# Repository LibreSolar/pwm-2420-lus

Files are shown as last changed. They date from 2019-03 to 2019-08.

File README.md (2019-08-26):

# PWM Solar Charge Controller (10-20A)

 Tested prototype, only minor issues left.

This PWM charge controller is cheaper than the MPPT charge controllers, as it does not contain the internal powerful DC/DC converter necessary for MPPT. The lower production cost and easy manufacturing with larger SMD components makes it ideally suited for solar home systems (SHS) for rural electrification.

The design allows to use either SMD MOSFETs or TO220 THT MOSFETs, which can be easily attached to a heat sink.

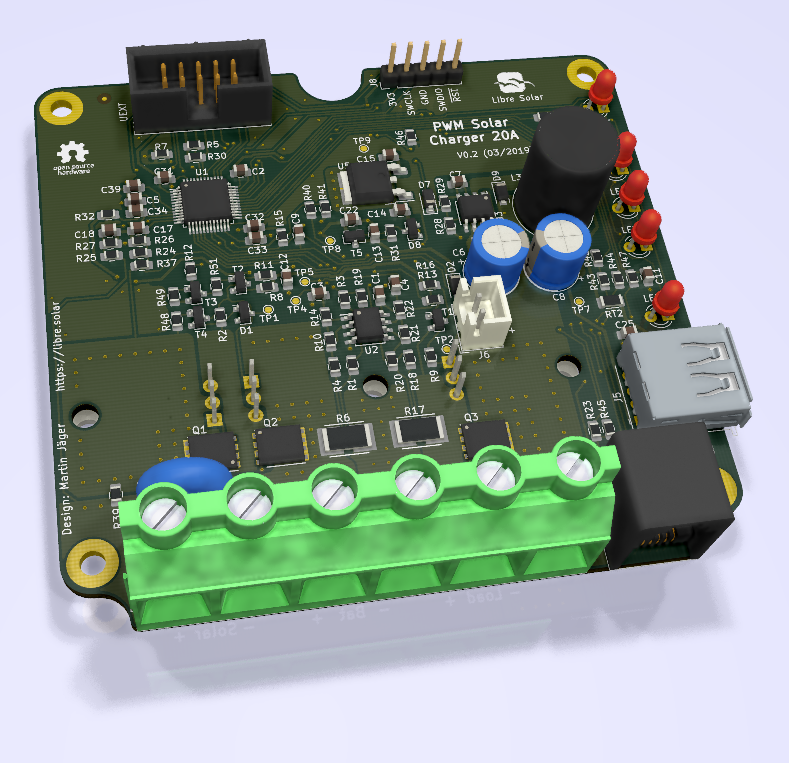
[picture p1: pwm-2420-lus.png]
PWM charge controller PCB


Schematic: [PDF file](pwm-2420-lus.pdf) in repository

Gerber files: [PCB ordering](http://libre.solar/docs/pcb_ordering) documentation

Bill of Materials: [BOM export](http://libre.solar/docs/bom) from KiCAD

Firmware: [Charge Controller Firmware](https://github.com/LibreSolar/charge-controller-firmware) repository

## Features:
- 12V/24V battery voltage
- Up to 20A max. charge current (depending on selected MOSFETs)
- 55V max. solar input
- 32bit ARM MCU (STM32L072)
- Expandable via Olimex Universal Extension Connector (UEXT) featuring
   I2C, Serial and SPI interface (e.g. used for display, WIFI communication, etc.)
- USB charging (single port)
- Low-side load switching

## Built-in protection
- Overvoltage
- Undervoltage
- Overcurrent
- PV short circuit
- PV reverse polarity (for max. module open circuit voltage of around 40V)
- Battery reverse polarity

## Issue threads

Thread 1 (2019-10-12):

Wrong load output current reading in v0.3

martinjaeger, 2019-10-12:
The voltage behind the output filter of the load current sense amplifier is used by a resistor divider to provide a threshold for the overcurrent comparator. This changes also the value read by the ADC, as it influences the overall output impedance.

Preliminary solution: Scale current sensor reading by a factor of  (12k+8.2k)/(39k+12k+8.2k) = 0.341.

Solution for next PCB revision: Separate signal for comparator and for current measurement right at the opamp output and not after the filter.

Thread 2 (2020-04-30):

Unstable power supply for battery voltages around 30V

martinjaeger, 2020-04-30:
See description of issue and solutions in Libre Solar forum:

https://talk.libre.solar/t/pwm2420-lus-for-battery-voltages-24v/

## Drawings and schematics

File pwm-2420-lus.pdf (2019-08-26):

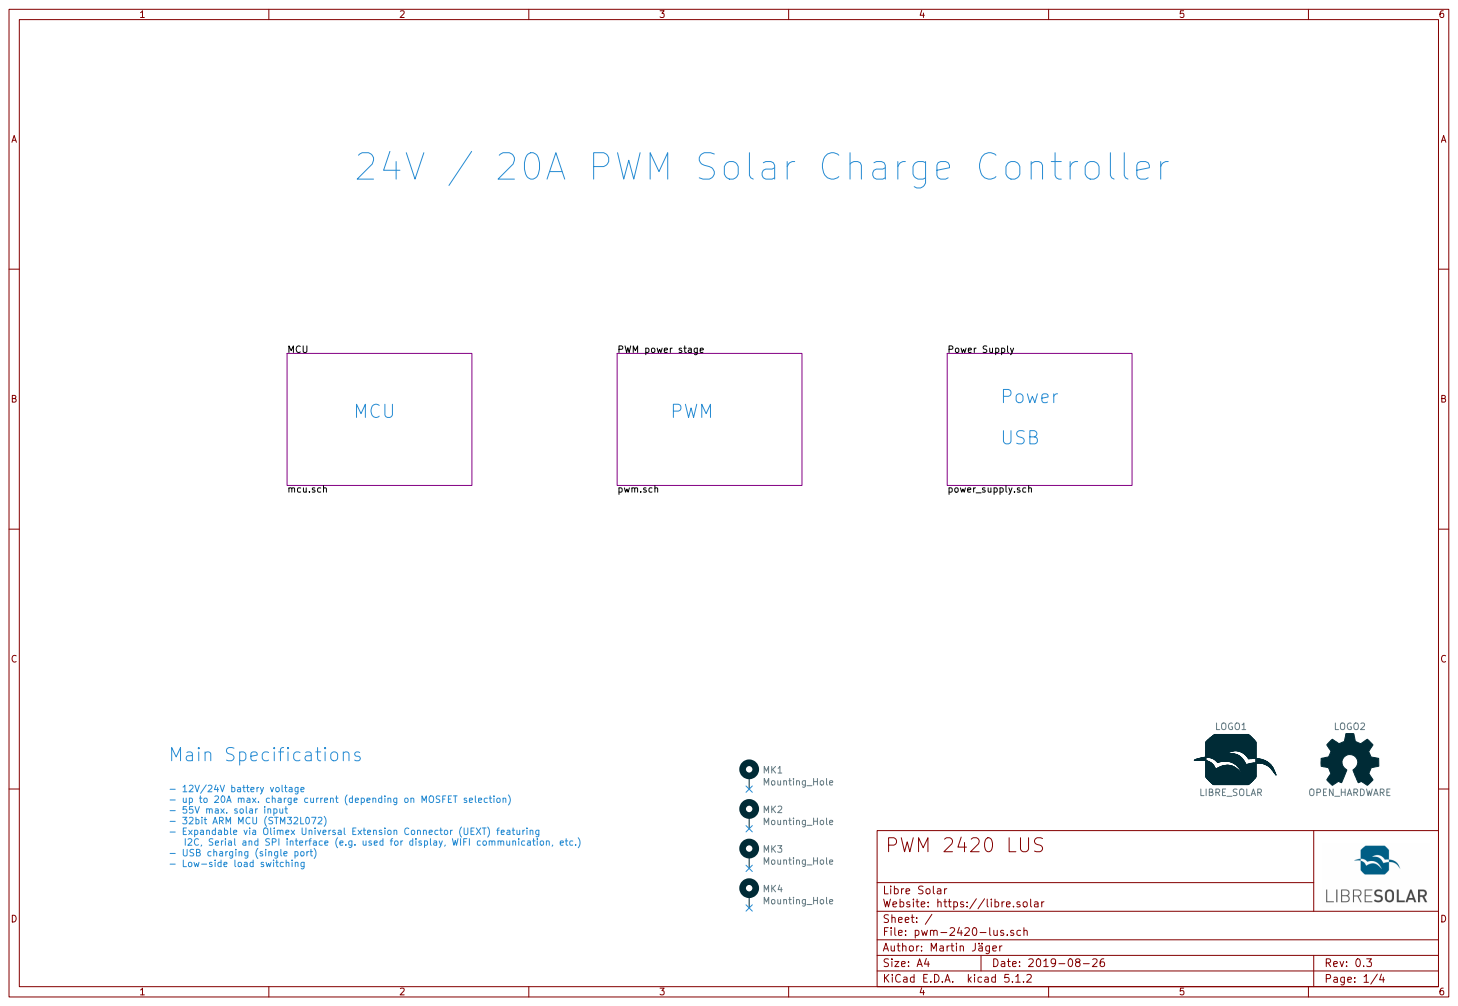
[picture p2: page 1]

24V / 20A PWM Solar Charge Controller

- 12V/24V battery voltage
- up to 20A max. charge current (depending on MOSFET selection)
- 55V max. solar input
- 32bit ARM MCU (STM32L072)
- Expandable via Olimex Universal Extension Connector (UEXT) featuring
I2C, Serial and SPI interface (e.g. used for display, WIFI communication, etc.)
- USB charging (single port)
- Low-side load switching

File: pwm-2420-lus.sch Sheet: / Libre Solar Author: Martin Jäger
Website: https://libre.solar

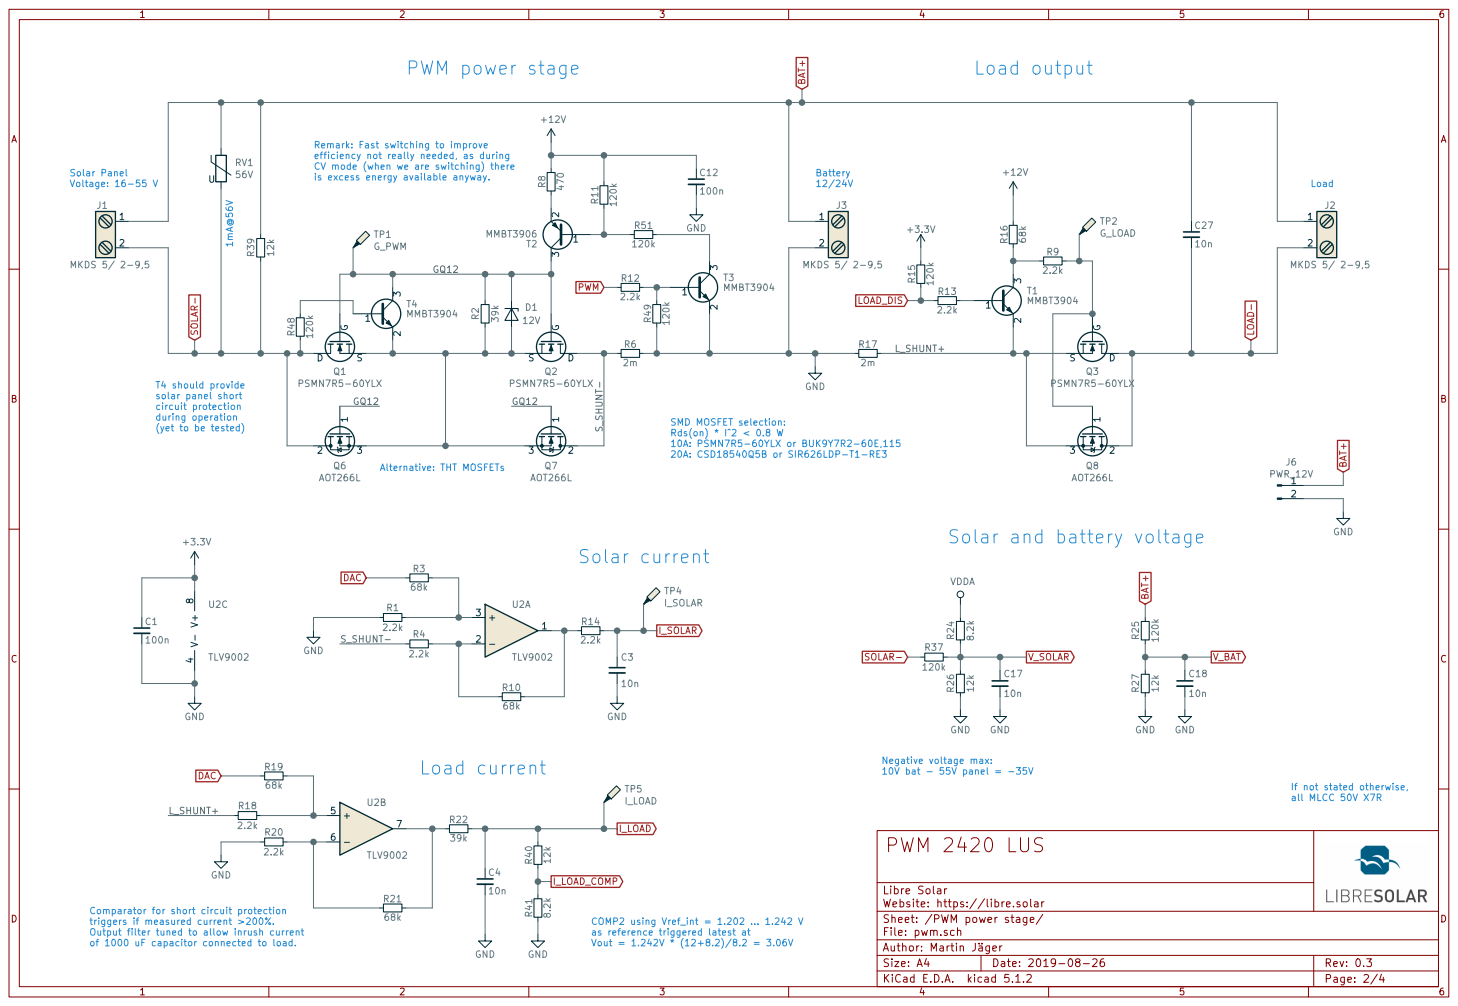
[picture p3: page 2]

20A: CSD18540Q5B or SIR626LDP-T1-RE3 Remark: Fast switching to improve
efficiency not really needed, as during
CV mode (when we are switching) there

J2 MKDS 5/ 2-9,5 Solar Panel Voltage: 16-55 V

2 3 T3MMBT3904 R11 120k SMD MOSFET selection: Rds(on) * I^2 < 0.8 W

solar panel short
circuit protection
during operation
(yet to be tested)

10n Solar and battery voltage

If not stated otherwise, all MLCC 50V X7R

Sheet: /PWM power stage/ Libre Solar Author: Martin Jäger
Website: https://libre.solar
File: pwm.sch

Comparator for short circuit protection
triggers if measured current >200%.
Output filter tuned to allow inrush current

as reference triggered latest at
Vout = 1.242V * (12+8.2)/8.2 = 3.06V

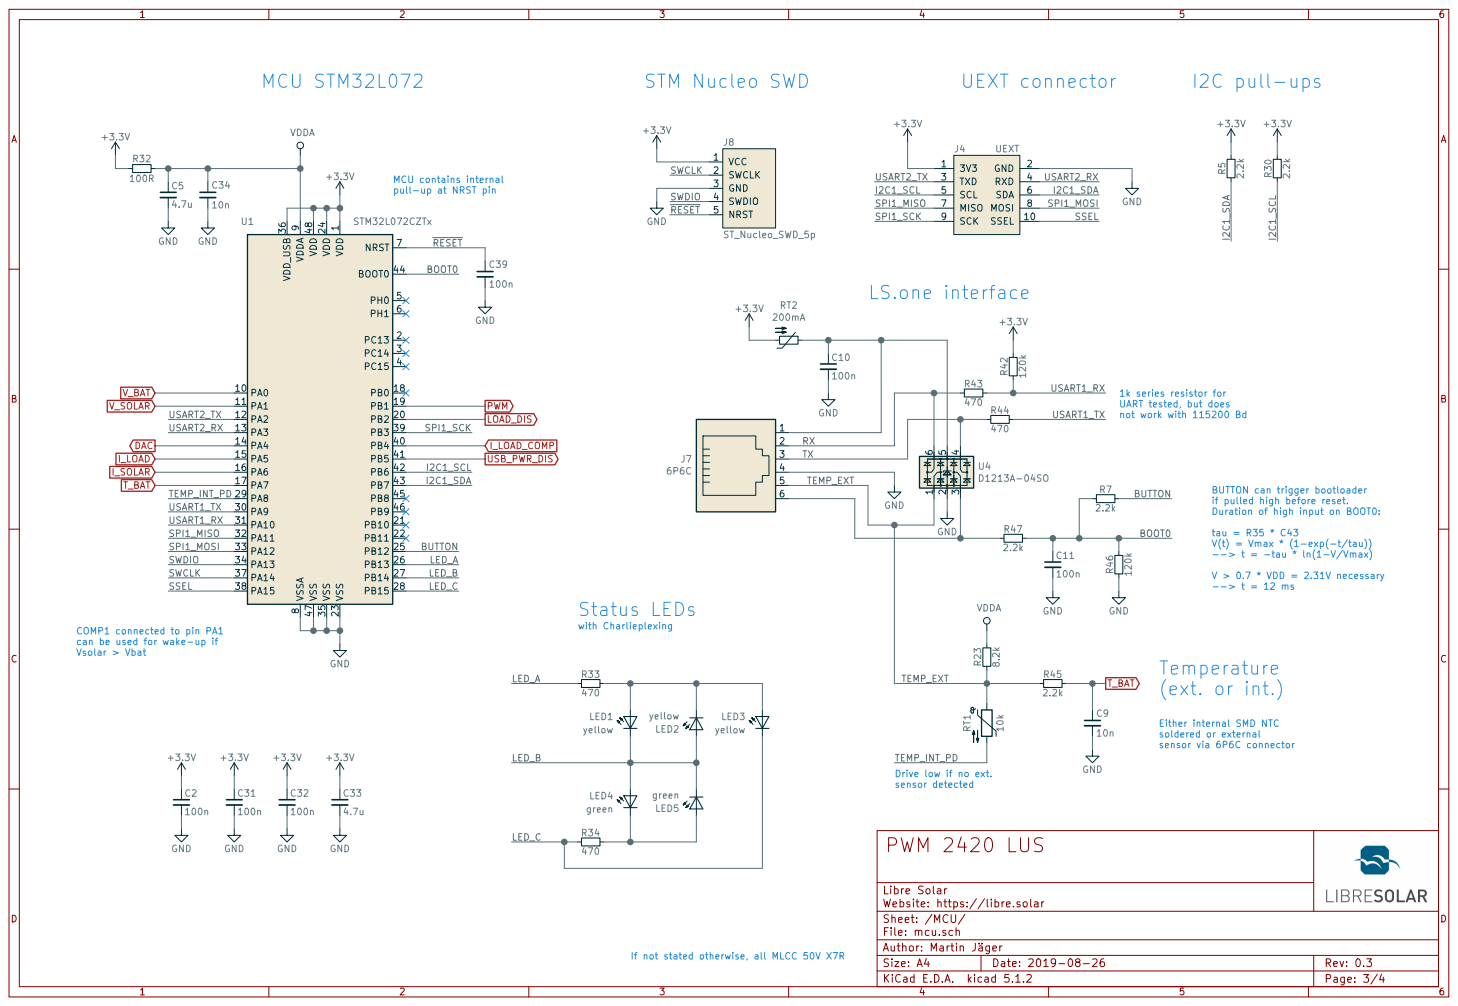
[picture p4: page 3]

100n GND MCU contains internal pull-up at NRST pin

9 VDD_USB 36 VSS 23 VSS 35 VSS 47 VSSA

soldered or external sensor via 6P6C connector LS.one interface
USART1_TX USART1_RX R45

1k series resistor for UART tested, but does not work with 115200 Bd +3.3V RX

BUTTON can trigger bootloader
if pulled high before reset.
Duration of high input on BOOT0:

tau = R35 * C43 V(t) = Vmax * (1-exp(-t/tau))

can be used for wake-up if Vsolar > Vbat

Drive low if no ext. sensor detected

File: mcu.sch Sheet: /MCU/ Libre Solar Author: Martin Jäger

If not stated otherwise, all MLCC 50V X7R

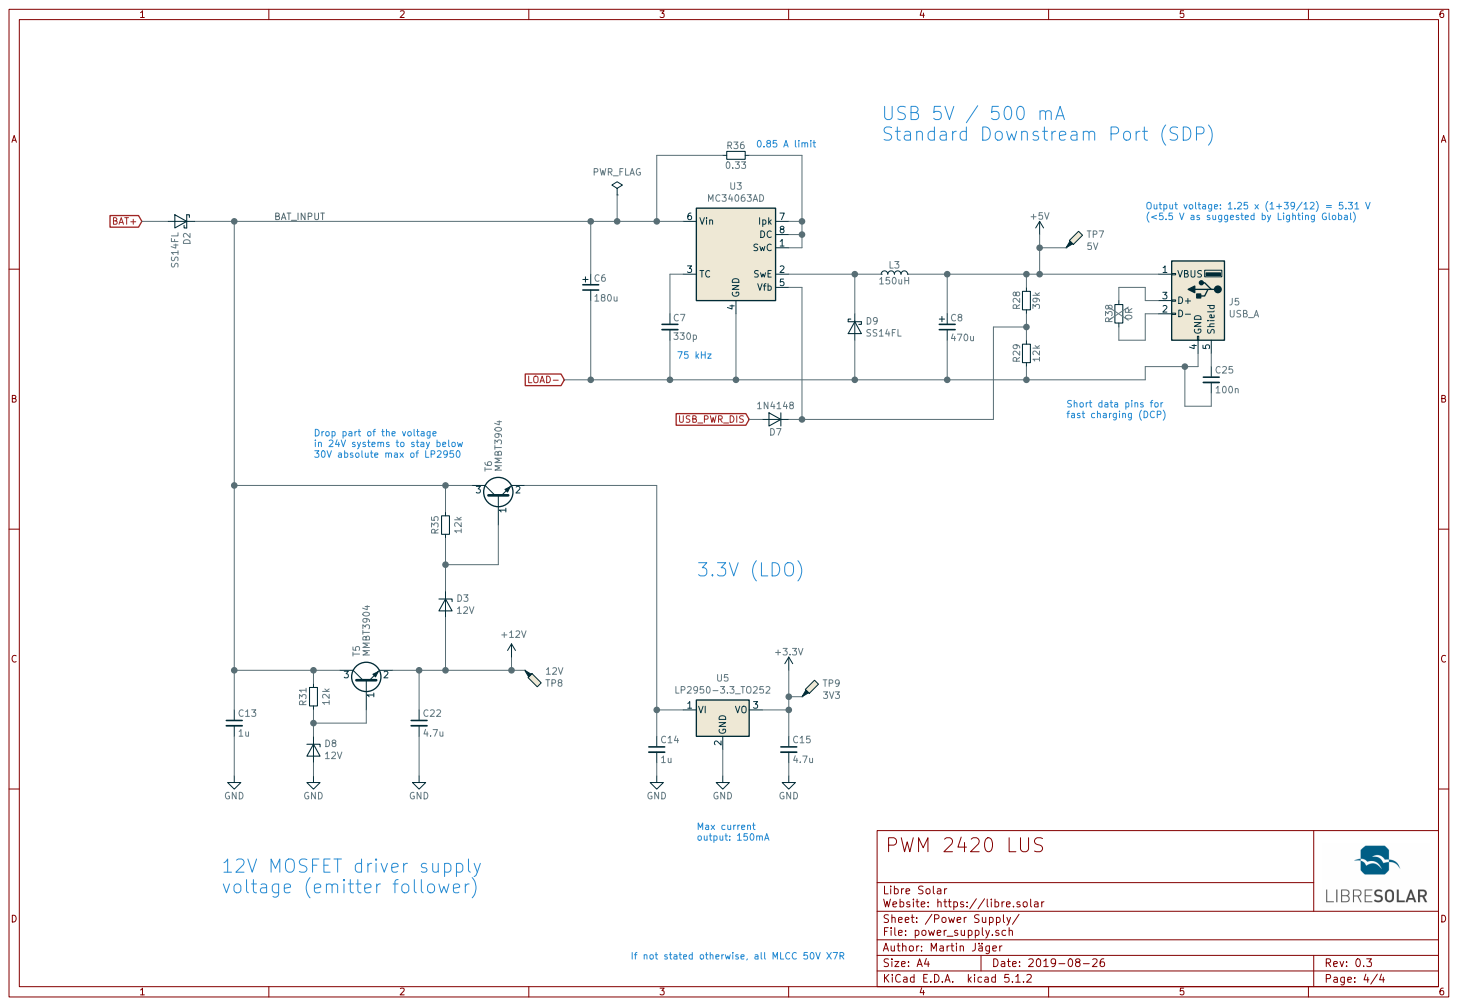
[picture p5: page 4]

Output voltage: 1.25 x (1+39/12) = 5.31 V
(<5.5 V as suggested by Lighting Global) C25

Short data pins for

Drop part of the voltage
in 24V systems to stay below

Sheet: /Power Supply/ Libre Solar Author: Martin Jäger

If not stated otherwise, all MLCC 50V X7R

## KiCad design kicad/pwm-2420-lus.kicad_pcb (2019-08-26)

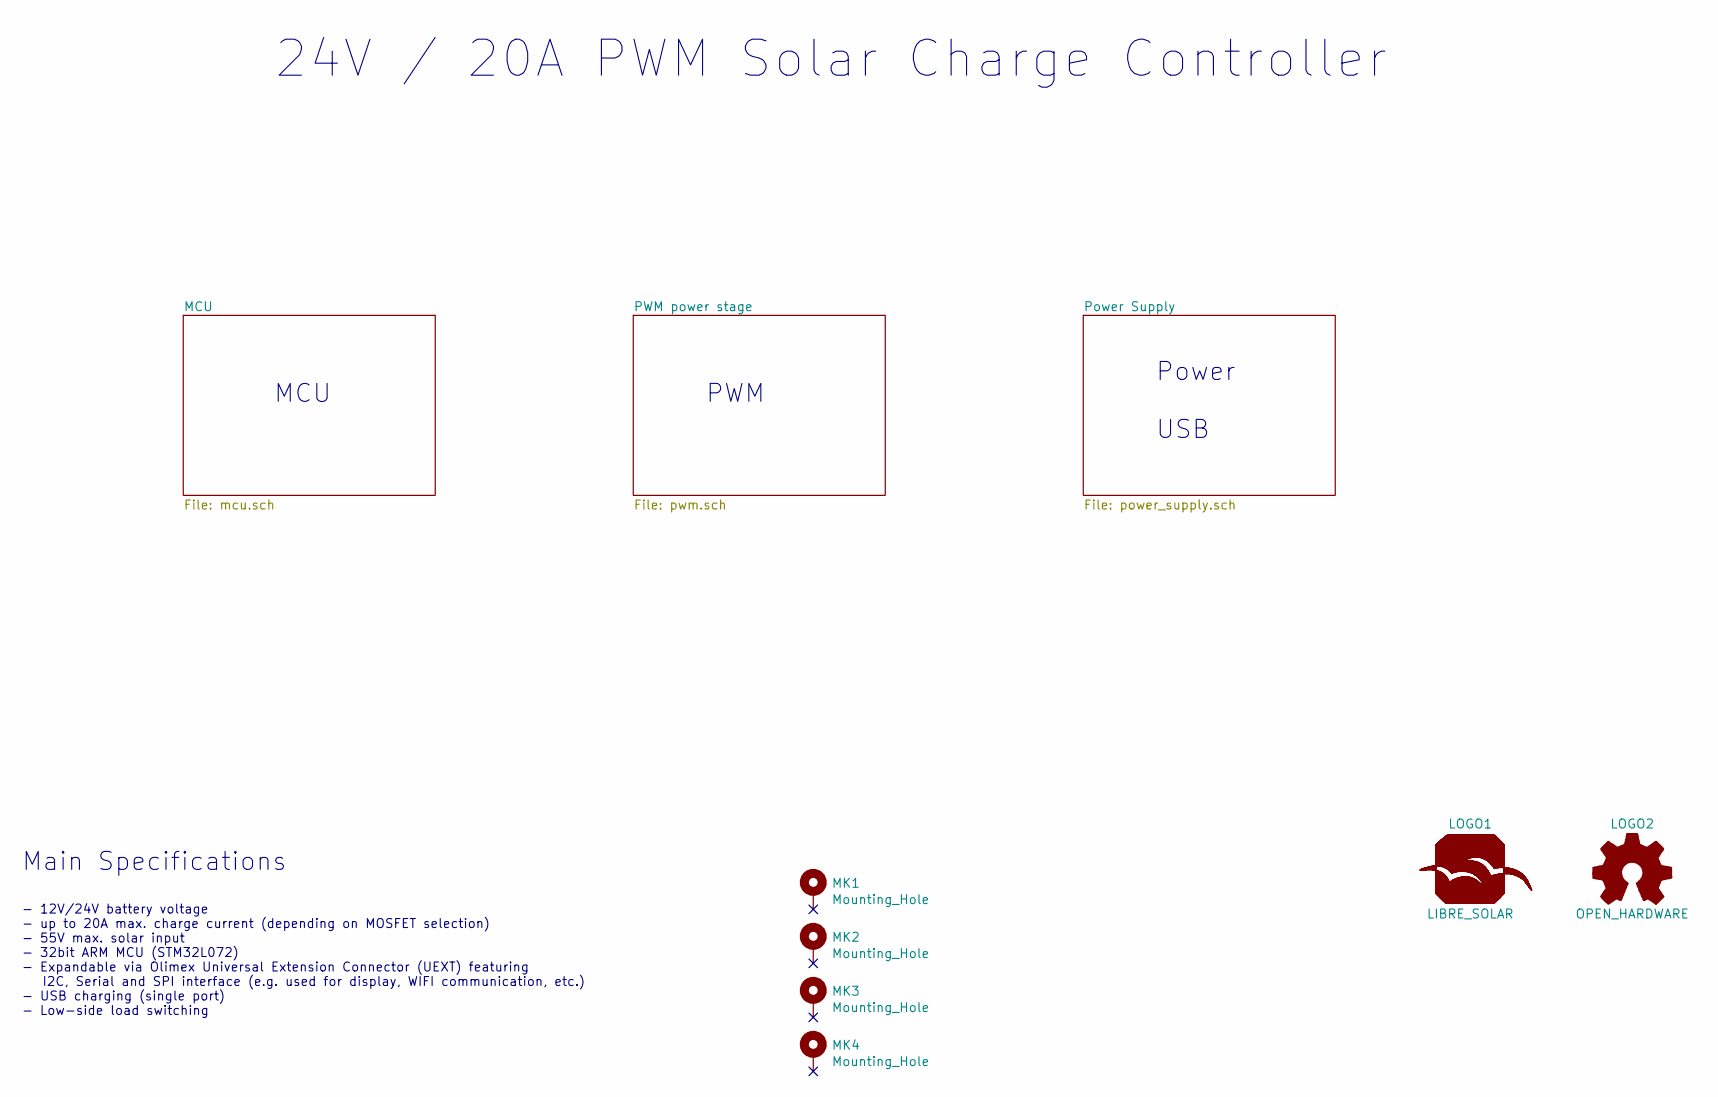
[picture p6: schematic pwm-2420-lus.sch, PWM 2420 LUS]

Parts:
LOGO1: LIBRE_SOLAR; LIBRESOLAR_LOGO
LOGO2: OPEN_HARDWARE; OSHW-Logo_5.7x6mm_SilkScreen
MK1, MK2, MK3, MK4: Mounting_Hole; MountingHole_3.2mm_M3_Pad

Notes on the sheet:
24V / 20A PWM Solar Charge Controller
Main Specifications
- 12V/24V battery voltage - up to 20A max. charge current (depending on MOSFET selection) - 55V max. solar input - 32bit ARM MCU (STM32L072) - Expandable via Olimex Universal Extension Connector (UEXT) featuring I2C, Serial and SPI interface (e.g. used for display, WIFI communication, etc.) - USB c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
PWM
MCU
Power USB

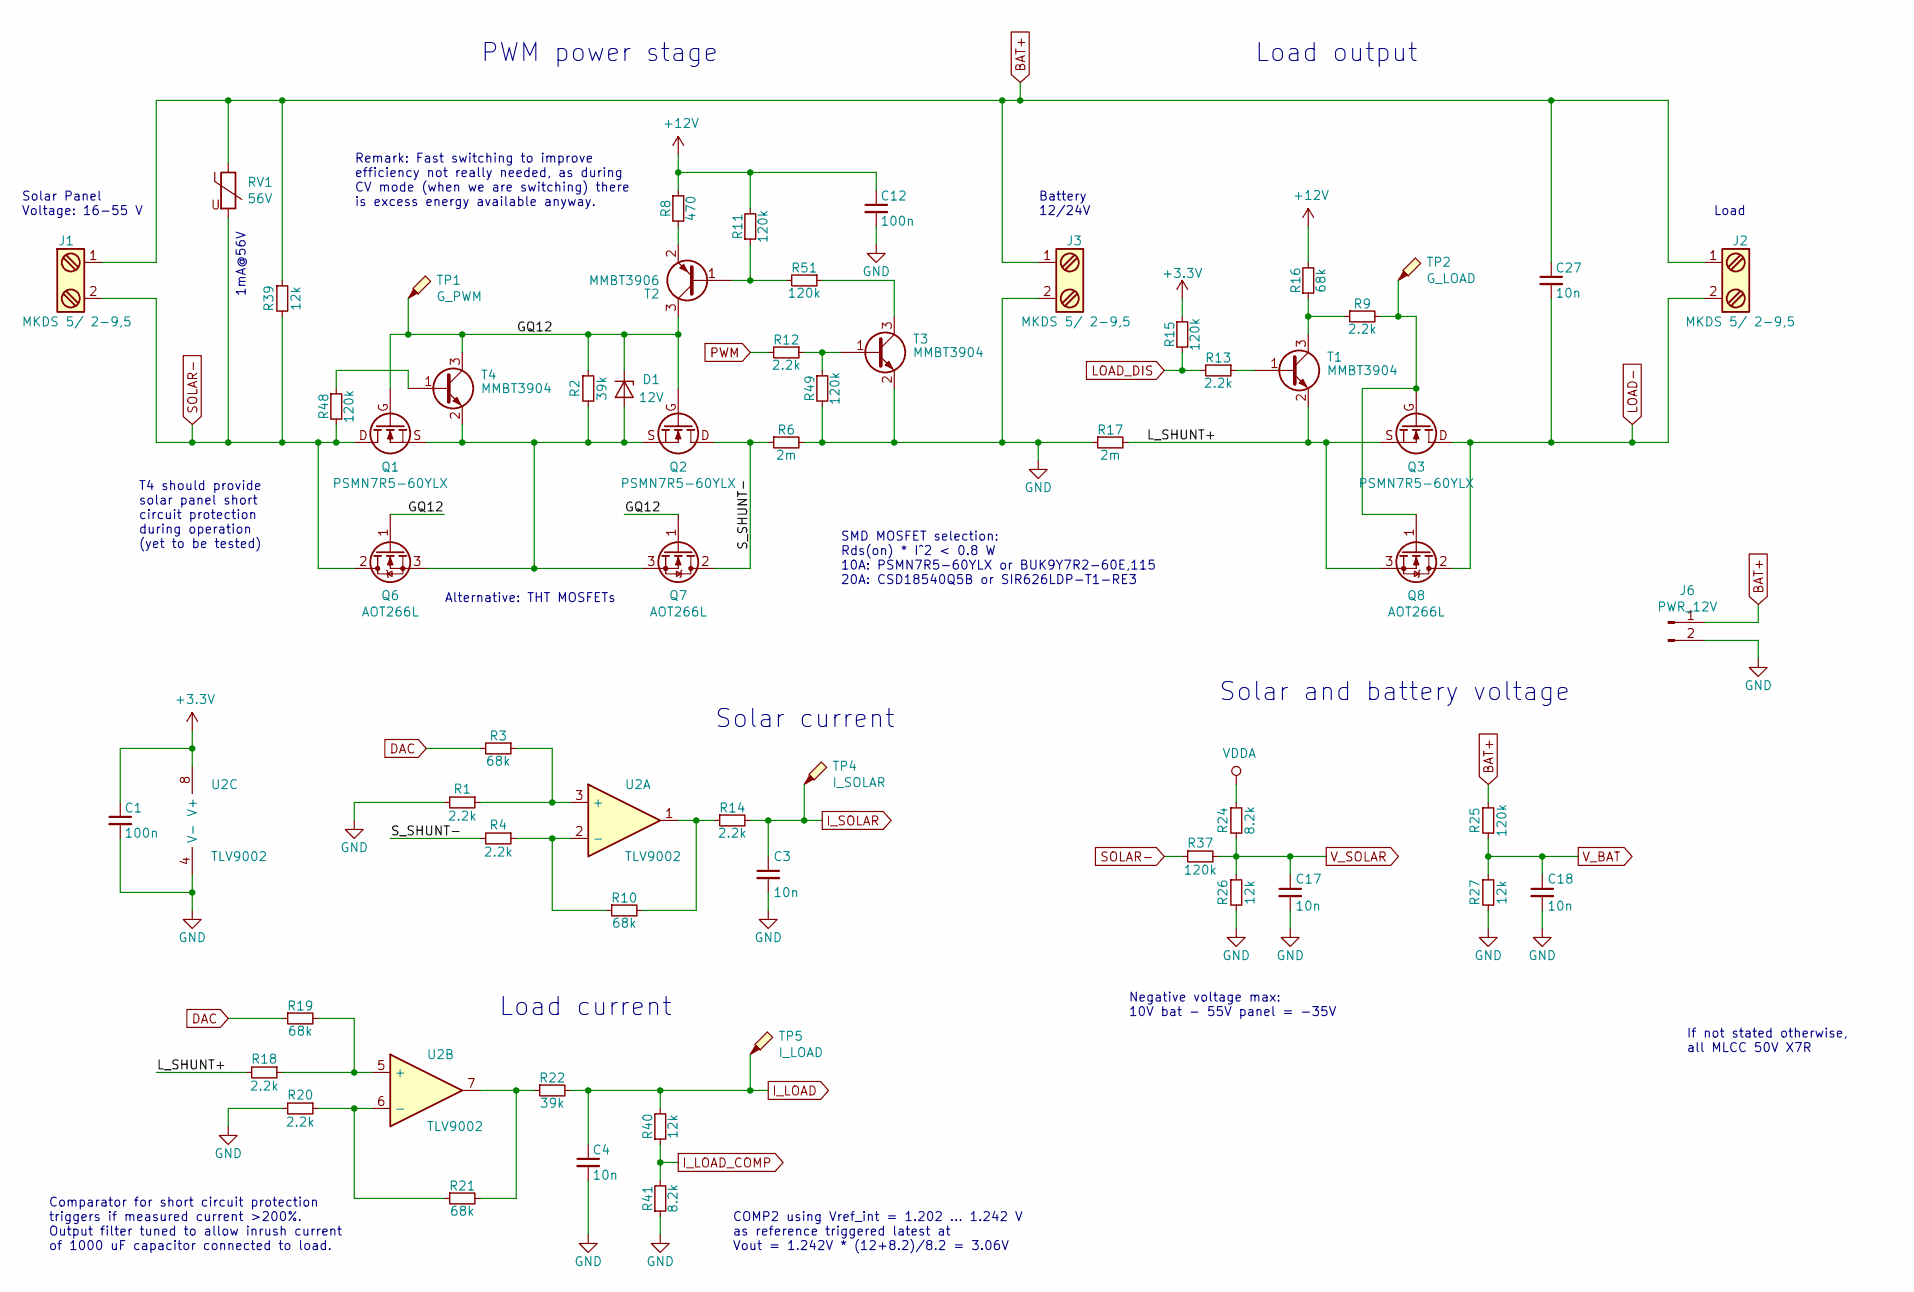
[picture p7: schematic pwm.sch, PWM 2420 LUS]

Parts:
C1, C12: 100n; C_0805_2012; PartNumber CC0805KRX7R9BB104
C3, C4, C17, C18, C27: 10n; C_0805_2012; PartNumber CC0805KRX7R0BB103
D1: 12V; D_SOT-23_ANK; PartNumber SZBZX84C12LT3G
J1, J2, J3: MKDS 5/ 2-9,5; Phoenix_Contact_MKDS_5-2-952; PartNumber 1714971
J6: PWR_12V; JST_XH_B02B-XH-A_1x02_P2.50mm_Vertical; PartNumber B2B-XH-A (LF)(SN)
Q1, Q2, Q3: PSMN7R5-60YLX; 5X6_MOSFET; PartNumber PSMN7R5-60YLX
Q6, Q7, Q8: AOT266L; TO-220-3_Horizontal_TabUp; PartNumber AOT266L
R1, R4, R9, R12, R13, R14, R18, R20: 2.2k; R_0805_2012; PartNumber RC0805FR-072K2L
R2: 39k; R_0805_2012; PartNumber RC0805FR-0739KL
R3, R10, R16, R19, R21: 68k; R_0805_2012; PartNumber RC0805FR-0768KL
R6, R17: 2m; R_Bourns_CRE2512; PartNumber CRE2512-FZ-R002E-3
R8: 470; R_0805_2012; PartNumber RC0805FR-07470RL
R11, R15, R25, R37, R48, R49, R51: 120k; R_0805_2012; PartNumber RC0805FR-07120KL
R22: 39k; R_0805_2012; PartNumber RC0805FR-0739K0L
R24, R41: 8.2k; R_0805_2012; PartNumber RC0805FR-078K2L
R26, R27, R39, R40: 12k; R_0805_2012; PartNumber RC0805FR-0712KL
RV1: 56V; RV_Disc_D12mm_W4.3mm_P7.5mm; PartNumber MOV-10D560K
T1, T3, T4: MMBT3904; SOT-23; PartNumber MMBT3904-7-F
T2: MMBT3906; SOT-23; PartNumber MMBT3906-7-F
TP1: G_PWM; TestPoint_Pad_D1.0mm
TP2: G_LOAD; TestPoint_Pad_D1.0mm
TP4: I_SOLAR; TestPoint_Pad_D1.0mm
TP5: I_LOAD; TestPoint_Pad_D1.0mm
U2: TLV9002; SOIC-8_3.9x4.9mm_Pitch1.27mm; PartNumber LM258DR

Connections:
+3V3: C1.1, R15.1, U2.8 (V+); also elsewhere on the board
+12V: C12.1, R8.1, R11.2, R16.2; also elsewhere on the board
/PWM power stage/GQ12: D1.1 (K), Q1.G, Q2.G, Q6.1 (G), Q7.1 (G), R2.1, T2.3 (C), T4.3 (C), TP1.1
/PWM power stage/L_SHUNT+: Q3.S, Q8.3 (S), R17.2, R18.2, T1.2 (E)
/PWM power stage/S_SHUNT-: Q2.D, Q7.2 (D), R4.2, R6.1
BAT+: C27.1, J1.1, J2.1, J3.1, J6.1, R25.1, R39.1, RV1.1; also elsewhere on the board
DAC: R3.2, R19.1; also elsewhere on the board
GND: C1.2, C3.2, C4.2, C12.2, C17.2, C18.2, J3.2, J6.2, R1.2, R6.2, R17.1, R20.2, R26.2, R27.2, R41.1, R49.2, T3.2 (E), U2.4 (V-); also elsewhere on the board
I_LOAD: C4.1, R22.2, R40.2, TP5.1; also elsewhere on the board
I_LOAD_COMP: R40.1, R41.2; also elsewhere on the board
I_SOLAR: C3.1, R14.2, TP4.1; also elsewhere on the board
LOAD-: C27.2, J2.2, Q3.D, Q8.2 (D); also elsewhere on the board
LOAD_DIS: R13.2, R15.2; also elsewhere on the board
unnamed: D1.2 (A), Q1.S, Q2.S, Q6.3 (S), Q7.3 (S), R2.2, T4.2 (E)
unnamed: Q3.G, Q8.1 (G), R9.2, TP2.1
unnamed: R1.1, R3.1, U2.3 (+)
unnamed: R8.2, T2.2 (E)
unnamed: R4.1, R10.1, U2.2 (-)
unnamed: R10.2, R14.1, U2.1
unnamed: R11.1, R51.2, T2.1 (B)
unnamed: R12.1, R49.1, T3.1 (B)
unnamed: R13.1, T1.1 (B)
unnamed: R9.1, R16.1, T1.3 (C)
unnamed: R18.1, R19.2, U2.5 (+)
unnamed: R20.1, R21.1, U2.6 (-)
unnamed: R21.2, R22.1, U2.7
unnamed: R48.1, T4.1 (B)
unnamed: R51.1, T3.3 (C)
PWM: R12.2; also elsewhere on the board
SOLAR-: J1.2, Q1.D, Q6.2 (D), R37.1, R39.2, R48.2, RV1.2
VDDA: R24.1; also elsewhere on the board
V_BAT: C18.1, R25.2, R27.1; also elsewhere on the board
V_SOLAR: C17.1, R24.2, R26.1, R37.2; also elsewhere on the board

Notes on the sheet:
Solar Panel Voltage: 16-55 V
PWM power stage
Load output
If not stated otherwise, all MLCC 50V X7R
Solar and battery voltage
SMD MOSFET selection: Rds(on) * I^2 < 0.8 W 10A: PSMN7R5-60YLX or BUK9Y7R2-60E,115 20A: CSD18540Q5B or SIR626LDP-T1-RE3
Remark: Fast switching to improve efficiency not really needed, as during CV mode (when we are switching) there is excess energy available anyway.
1mA@56V
Load current
Solar current
Negative voltage max: 10V bat - 55V panel = -35V
Comparator for short circuit protection triggers if measured current >200%. Output filter tuned to allow inrush current of 1000 uF capacitor connected to load.
Alternative: THT MOSFETs
COMP2 using Vref_int = 1.202 ... 1.242 V as reference triggered latest at Vout = 1.242V * (12+8.2)/8.2 = 3.06V
Battery 12/24V
Load
T4 should provide solar panel short circuit protection during operation (yet to be tested)

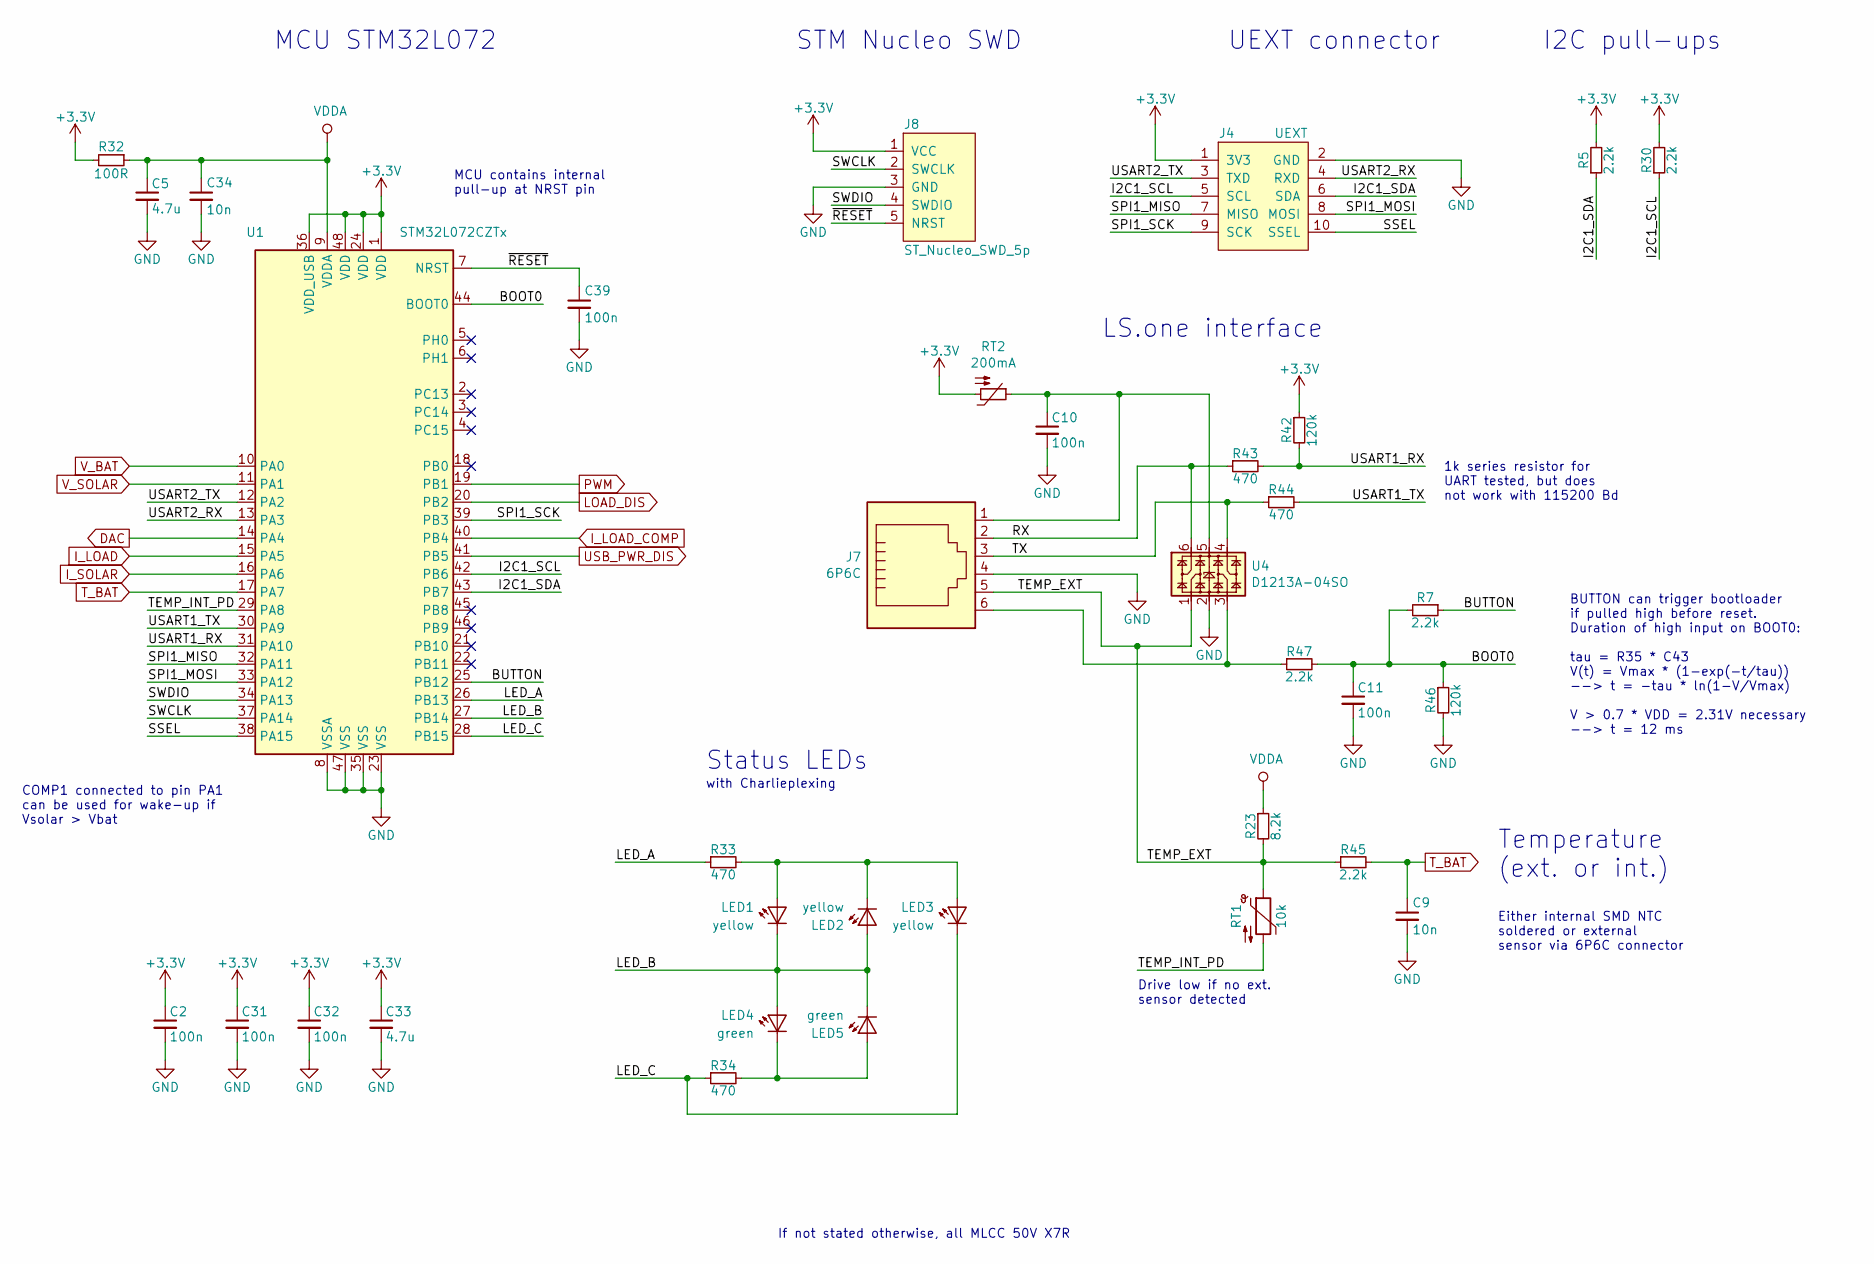
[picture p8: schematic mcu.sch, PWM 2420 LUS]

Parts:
C2, C10, C11, C31, C32, C39: 100n; C_0805_2012; PartNumber CC0805KRX7R9BB104
C5, C33: 4.7u; C_0805_2012; PartNumber 885012107018
C9, C34: 10n; C_0805_2012; PartNumber CC0805KRX7R0BB103
J4: UEXT; Box_Header_2x05x2.54mm_Straight; PartNumber 302-S101
J7: 6P6C; RJ25_6P6C_TabUp; PartNumber 615006138421
J8: ST_Nucleo_SWD_5p; PinHeader_1x05_P2.54mm_Vertical
LED1, LED3: yellow; LED_0603_D3.0mm; PartNumber LTL-1CHY
LED2, LED5: green; LED_0603_D3.0mm; PartNumber LTL-4231
R5, R7, R30, R45, R47: 2.2k; R_0805_2012; PartNumber RC0805FR-072K2L
R23: 8.2k; R_0805_2012; PartNumber RC0805FR-078K2L
R32: 100R; R_0805_2012; PartNumber RC0805FR-07100RL
R33, R34, R43, R44: 470; R_0805_2012; PartNumber RC0805FR-07470RL
R42, R46: 120k; R_0805_2012; PartNumber RC0805FR-07120KL
RT1: 10k; R_0805_2012; PartNumber NCP21XV103J03RA
RT2: 200mA; R_1206_3216; PartNumber 0ZCJ0020FF2E
U1: STM32L072CZTx; LQFP-48_7x7mm_P0.5mm; PartNumber STM32L072CZT6
U4: D1213A-04SO; SOT-23-6; PartNumber D1213A-04SO

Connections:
+3V3: C2.1, C31.1, C32.1, C33.1, J4.1 (3V3), J8.1 (VCC), R5.2, R30.2, R32.2, R42.1, RT2.2, U1.1 (VDD), U1.24 (VDD), U1.36 (VDD_USB), U1.48 (VDD); also elsewhere on the board
/MCU/BOOT0: C11.1, R7.2, R46.1, R47.2, U1.44 (BOOT0)
/MCU/BUTTON: R7.1, U1.25 (PB12)
/MCU/I2C1_SCL: J4.5 (SCL), R30.1, U1.42 (PB6)
/MCU/I2C1_SDA: J4.6 (SDA), R5.1, U1.43 (PB7)
/MCU/LED_A: R33.1, U1.26 (PB13)
/MCU/LED_B: LED1.1 (K), LED2.2 (A), LED5.1 (K), U1.27 (PB14); also elsewhere on the board
/MCU/LED_C: LED3.1 (K), R34.1, U1.28 (PB15)
/MCU/RX: J7.2, R43.1, U4.6
/MCU/SPI1_MISO: J4.7 (MISO), U1.32 (PA11)
/MCU/SPI1_MOSI: J4.8 (MOSI), U1.33 (PA12)
/MCU/SPI1_SCK: J4.9 (SCK), U1.39 (PB3)
/MCU/SSEL: J4.10 (SSEL), U1.38 (PA15)
/MCU/SWCLK: J8.2 (SWCLK), U1.37 (PA14)
/MCU/SWDIO: J8.4 (SWDIO), U1.34 (PA13)
/MCU/TEMP_EXT: J7.5, R23.2, R45.1, RT1.1, U4.1
/MCU/TEMP_INT_PD: RT1.2, U1.29 (PA8)
/MCU/TX: J7.3, R44.1, U4.4
/MCU/USART1_RX: R42.2, R43.2, U1.31 (PA10)
/MCU/USART1_TX: R44.2, U1.30 (PA9)
/MCU/USART2_RX: J4.4 (RXD), U1.13 (PA3)
/MCU/USART2_TX: J4.3 (TXD), U1.12 (PA2)
/MCU/~RESET: C39.1, J8.5 (NRST), U1.7 (NRST)
DAC: U1.14 (PA4); also elsewhere on the board
GND: C2.2, C5.2, C9.2, C10.2, C11.2, C31.2, C32.2, C33.2, C34.2, C39.2, J4.2 (GND), J7.4, J8.3 (GND), R46.2, U1.8 (VSSA), U1.23 (VSS), U1.35 (VSS), U1.47 (VSS), U4.2; also elsewhere on the board
I_LOAD: U1.15 (PA5); also elsewhere on the board
I_LOAD_COMP: U1.40 (PB4); also elsewhere on the board
I_SOLAR: U1.16 (PA6); also elsewhere on the board
LOAD_DIS: U1.20 (PB2); also elsewhere on the board
unnamed: C10.1, J7.1, RT2.1, U4.5
unnamed: J7.6, R47.1, U4.3
PWM: U1.19 (PB1); also elsewhere on the board
T_BAT: C9.1, R45.2, U1.17 (PA7)
USB_PWR_DIS: U1.41 (PB5); also elsewhere on the board
VDDA: C5.1, C34.1, R23.1, R32.1, U1.9 (VDDA); also elsewhere on the board
V_BAT: U1.10 (PA0); also elsewhere on the board
V_SOLAR: U1.11 (PA1); also elsewhere on the board

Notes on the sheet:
Status LEDs
MCU STM32L072
STM Nucleo SWD
If not stated otherwise, all MLCC 50V X7R
UEXT connector
I2C pull-ups
MCU contains internal pull-up at NRST pin
with Charlieplexing
Temperature (ext. or int.)
Either internal SMD NTC soldered or external sensor via 6P6C connector
LS.one interface
COMP1 connected to pin PA1 can be used for wake-up if Vsolar > Vbat
Drive low if no ext. sensor detected
1k series resistor for UART tested, but does not work with 115200 Bd
BUTTON can trigger bootloader if pulled high before reset. Duration of high input on BOOT0: tau = R35 * C43 V(t) = Vmax * (1-exp(-t/tau)) --> t = -tau * ln(1-V/Vmax) V > 0.7 * VDD = 2.31V necessary --> t = 12 ms

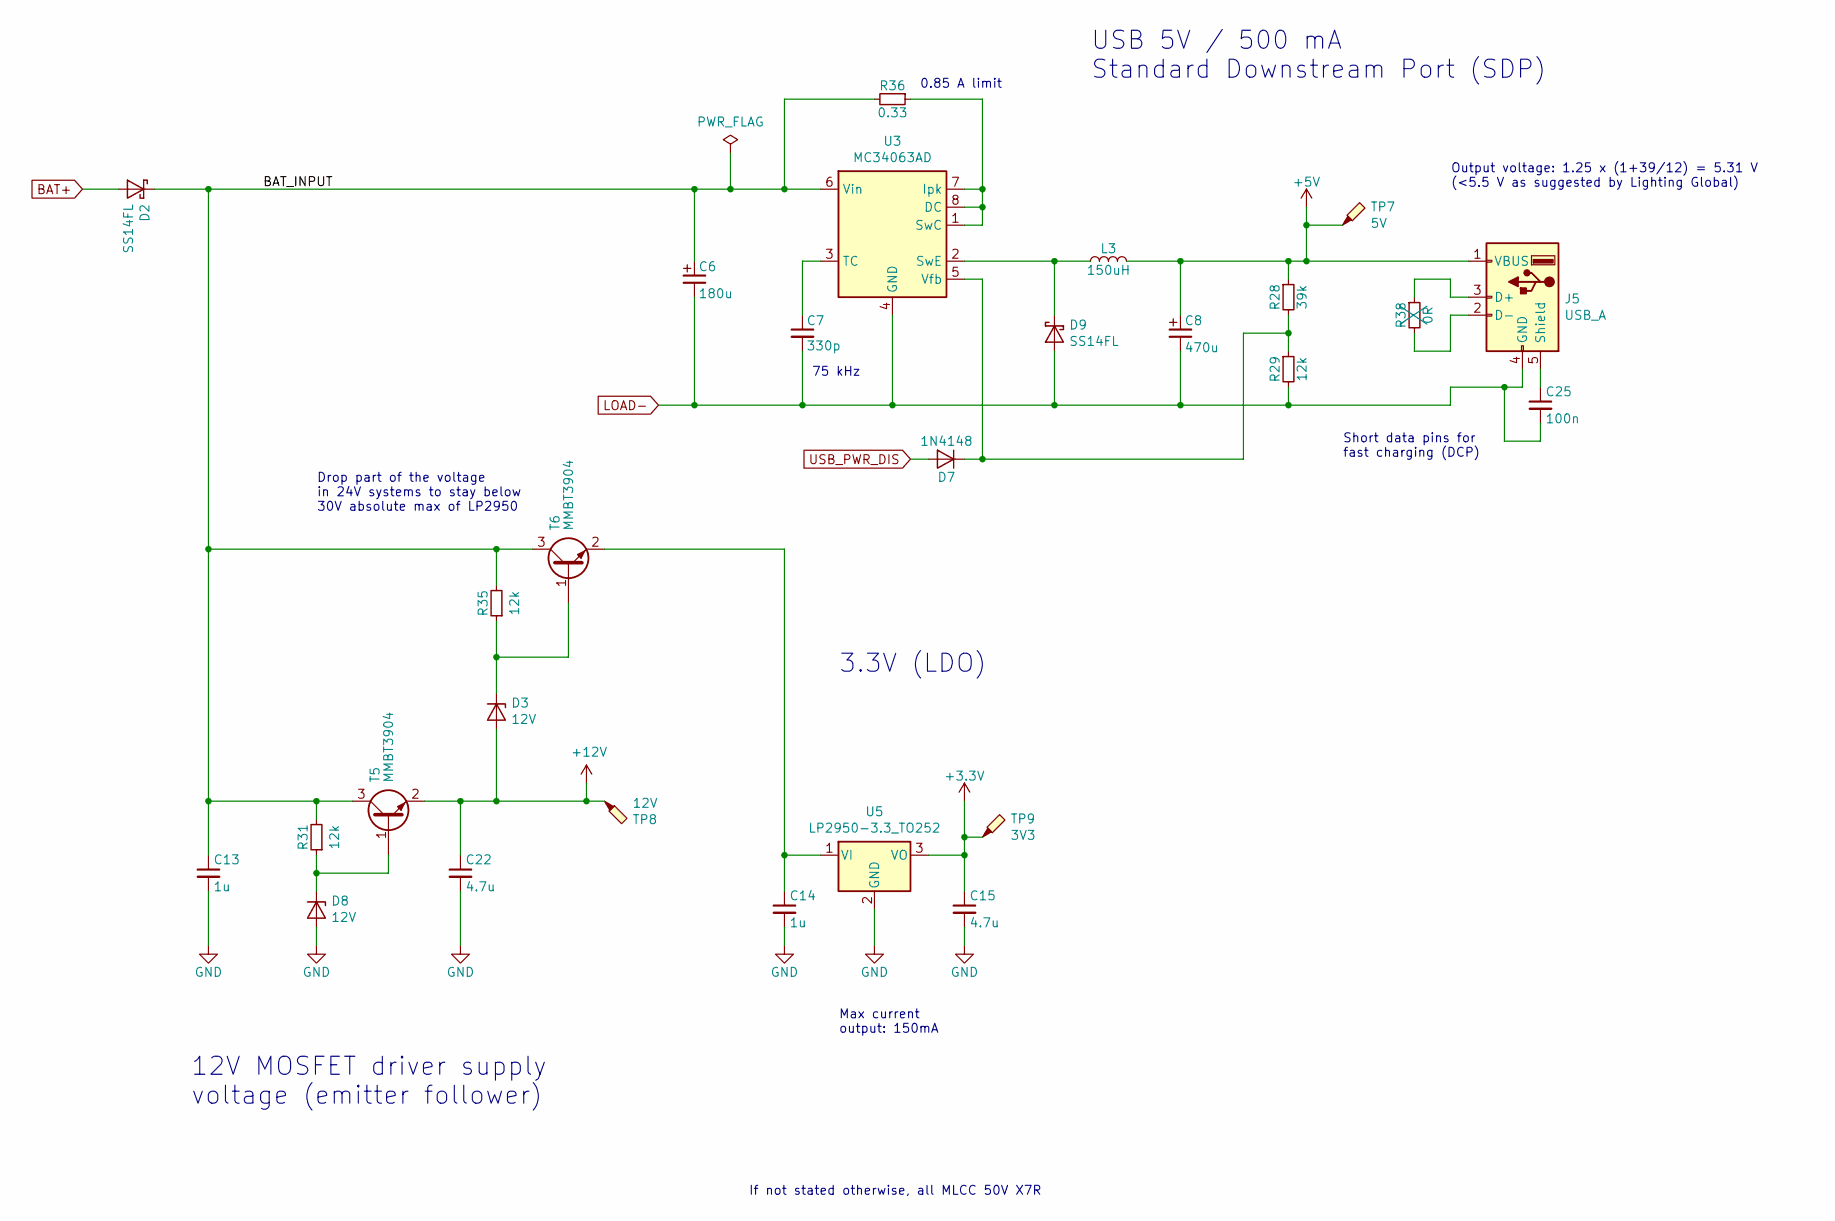
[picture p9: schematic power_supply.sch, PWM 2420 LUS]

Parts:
C6: 180u; CP_Radial_D8.0mm_P3.50mm; PartNumber EEU-FR1V181
C7: 330p; C_0805_2012; PartNumber 885342007002
C8: 470u; CP_Radial_D8.0mm_P3.50mm; PartNumber EEUFR1A471
C13, C14: 1u; C_0805_2012; PartNumber CC0805KKX7R9BB105
C15, C22: 4.7u; C_0805_2012; PartNumber 885012107018
C25: 100n; C_0805_2012; PartNumber CC0805KRX7R9BB104
D2, D9: SS14FL; D_SOD-123F; PartNumber SS14FL
D3, D8: 12V; D_SOT-23_ANK; PartNumber SZBZX84C12LT3G
D7: 1N4148; D_SOD-123; PartNumber 1N4148W-7-F
J5: USB_A; USB_A_Wuerth_61400416021_Horizontal; PartNumber 61400416021
L3: 150uH; L_Radial_D12.0mm_P5.00mm_Fastron_11P; PartNumber RLB0914-151KL
R28: 39k; R_0805_2012; PartNumber RC0805FR-0739KL
R29, R31, R35: 12k; R_0805_2012; PartNumber RC0805FR-0712KL
R36: 0.33; R_1206_3216; PartNumber RL1206FR-070R33L
R38: 0R; R_0805_2012; PartNumber RC0805FR-070RL
T5, T6: MMBT3904; SOT-23; PartNumber MMBT3904-7-F
TP7: 5V; TestPoint_Pad_D1.0mm
TP8: 12V; TestPoint_Pad_D1.0mm
TP9: 3V3; TestPoint_Pad_D1.0mm
U3: MC34063AD; SOIC-8_3.9x4.9mm_P1.27mm; PartNumber MC34063ADR
U5: LP2950-3.3_TO252; TO-252-2; PartNumber LP2950ACDT-3.3RG

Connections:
+3V3: C15.1, TP9.1, U5.3 (VO); also elsewhere on the board
+5V: C8.1, J5.1 (VBUS), L3.2, R28.1, TP7.1
+12V: C22.1, D3.2 (A), T5.2 (E), TP8.1; also elsewhere on the board
/Power Supply/BAT_INPUT: C6.1, C13.1, D2.1 (K), R31.2, R35.2, R36.2, T5.3 (C), T6.3 (C), U3.6 (Vin)
BAT+: D2.2 (A); also elsewhere on the board
GND: C13.2, C14.2, C15.2, C22.2, D8.2 (A), U5.2 (GND); also elsewhere on the board
LOAD-: C6.2, C7.2, C8.2, C25.2, D9.2 (A), J5.4 (GND), R29.2, U3.4 (GND); also elsewhere on the board
unnamed: C7.1, U3.3 (TC)
unnamed: C14.1, T6.2 (E), U5.1 (VI)
unnamed: C25.1, J5.5 (Shield)
unnamed: D3.1 (K), R35.1, T6.1 (B)
unnamed: D7.1 (K), R28.2, R29.1, U3.5 (Vfb)
unnamed: D8.1 (K), R31.1, T5.1 (B)
unnamed: D9.1 (K), L3.1, U3.2 (SwE)
unnamed: J5.2 (D-), R38.2
unnamed: J5.3 (D+), R38.1
unnamed: R36.1, U3.1 (SwC), U3.7 (Ipk), U3.8 (DC)
USB_PWR_DIS: D7.2 (A); also elsewhere on the board

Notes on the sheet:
Max current output: 150mA
USB 5V / 500 mA Standard Downstream Port (SDP)
3.3V (LDO)
If not stated otherwise, all MLCC 50V X7R
Output voltage: 1.25 x (1+39/12) = 5.31 V (<5.5 V as suggested by Lighting Global)
12V MOSFET driver supply voltage (emitter follower)
Short data pins for fast charging (DCP)
75 kHz
0.85 A limit
Drop part of the voltage in 24V systems to stay below 30V absolute max of LP2950

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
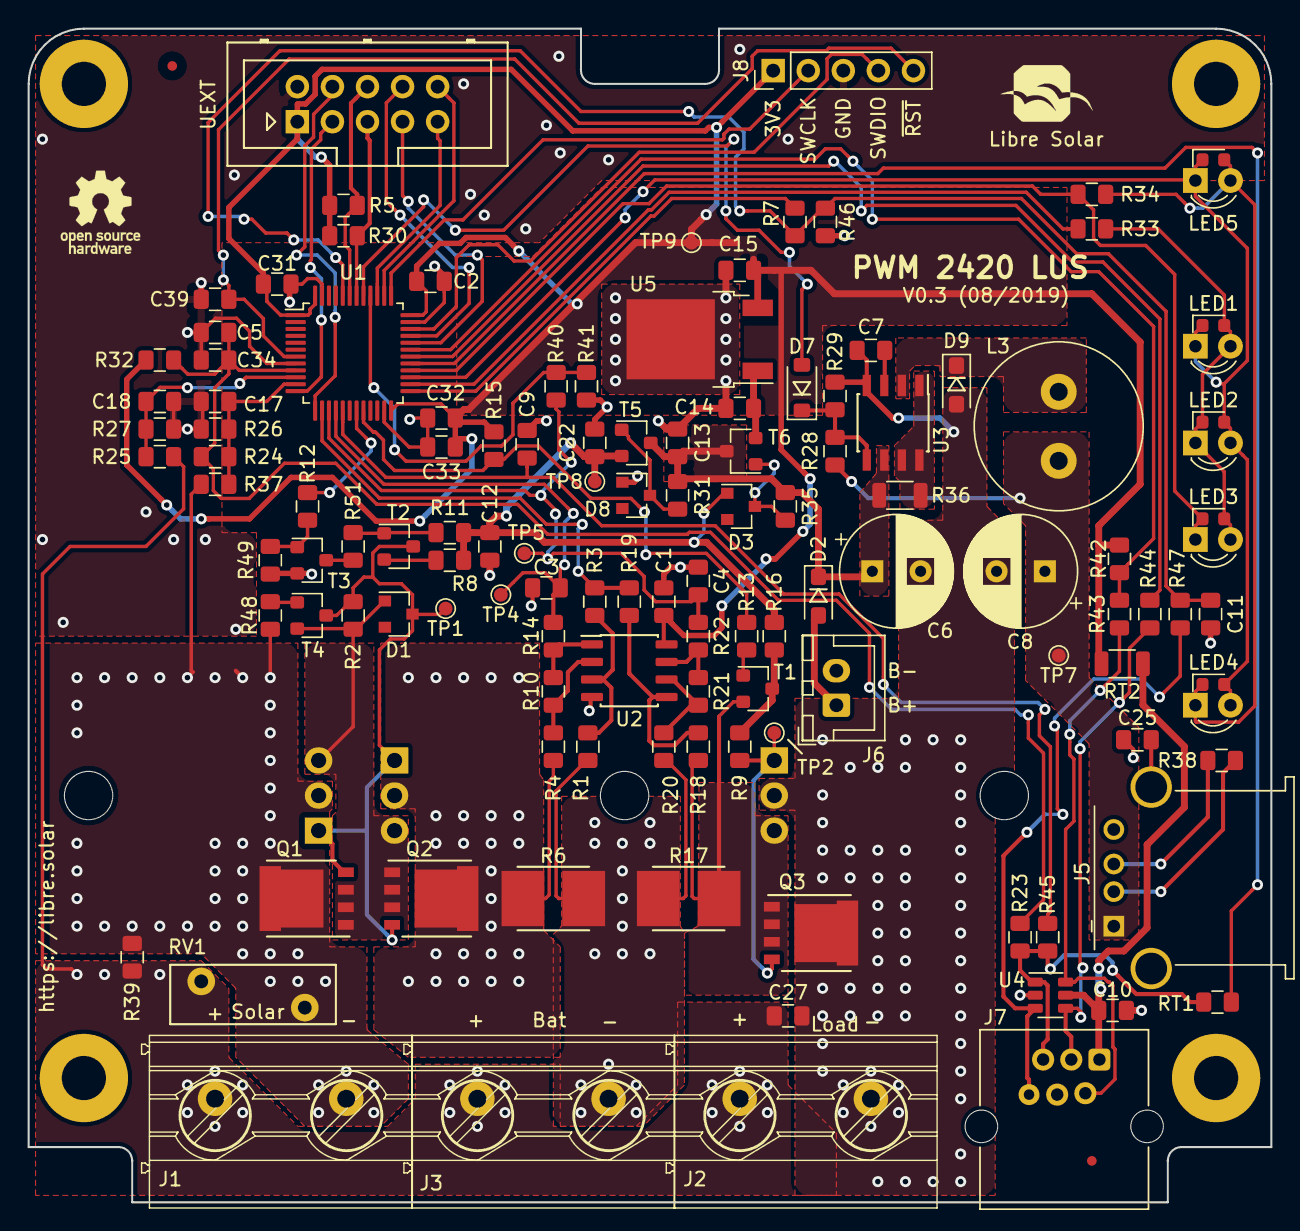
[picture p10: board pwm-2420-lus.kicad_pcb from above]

Board: 2 copper layers, 90.0 x 85.0 mm, 128 parts (0 on the bottom side), 73 nets.

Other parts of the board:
LED4: green; LED_0603_D3.0mm

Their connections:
/MCU/LED_B: LED4.2; also elsewhere on the board

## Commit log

2019-04-26 Updates after manufacturer feedback
    [mcu.sch, power_supply.sch, pwm.sch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]
2019-08-15 Folder restructured and files renamed
    [mcu.sch, power_supply.sch, pwm-2420-lus.kicad_pcb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]
2019-08-16 Load current sense filter and comparator updated
    [mcu.sch, power_supply.sch, pwm-2420-lus.kicad_pcb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]
2019-08-26 Improved power supply and exposed BOOT0 pin
    - BOOT0 pin connected to BUTTON wire to allow firmware upgrade via LS.one port
    - Additional emitter follower for 3V3 power supply to increase margin to 30V absolute max. rating of LDO in case of 24V battery
    - Corners adjusted to match shape of MPPT 1210 HUS
    [mcu.sch, power_supply.sch, pwm-2420-lus.kicad_pcb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]
